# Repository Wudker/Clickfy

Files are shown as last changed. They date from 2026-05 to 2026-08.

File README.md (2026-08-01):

# Clickfy – BLE Multimedia Remote

Clickfy is a compact, keychain-sized multimedia remote based on the ESP32-C3. It communicates through the BLE HID profile and provides dedicated controls for play/pause, next track and previous track. A custom PCB integrates the control buttons, Li-Po battery, status LED and battery-voltage monitoring circuit. The firmware uses sleep modes to reduce power consumption, with development focused on minimizing wake-up and BLE reconnection times.

## Technologies

`ESP32-C3` `C/C++` `Bluetooth Low Energy` `BLE HID` `Li-Po battery` `ADC battery monitoring` `Custom PCB` `Low-power operation`

## Usage and development status

After powering on the device, pair Clickfy with a phone, computer or another BLE-compatible media device and use the three buttons to control playback. The current prototype has been built and tested. Planned improvements include further power optimization, shorter reconnection times and support for additional multimedia functions.

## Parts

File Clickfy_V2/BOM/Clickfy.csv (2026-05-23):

Reference | Qty | Value | Footprint
C1,C3,C6,C7,C11,C14,C15 | 7 | 100n | Capacitor_SMD:C_1206_3216Metric
C2,C10,C12 | 3 | 22u | Capacitor_THT:C_Radial_D4.0mm_H7.0mm_P1.50mm
C4 | 1 | 22u | Capacitor_THT:C_Radial_D5.0mm_H11.0mm_P2.00mm
C5,C8 | 2 | 4.7u
C9,C13 | 2 | 10u
D1 | 1 | LED | LED_THT:LED_D5.0mm
D2,D3 | 2 | LED | LED_SMD:LED_1206_3216Metric
D4 | 1 | SS34 | Diode_SMD:D_SMC
J1 | 1 | USB_C_Receptacle_USB2.0_16P | Connector_USB:USB_C_Receptacle_GCT_USB4125-xx-x_6P_TopMnt_Horizontal
Q1 | 1 | PUMX1 | Package_TO_SOT_SMD:SOT-363_SC-70-6
Q3 | 1 | AO3401A | Package_TO_SOT_SMD:SOT-23
R1,R2,R3,R4,R7,R8,R10,R11,R16,R19,R20 | 11 | 10k | Resistor_SMD:R_1206_3216Metric
R5,R6 | 2 | 5.1K
R9,R12,R13 | 3 | 1k | Resistor_SMD:R_1206_3216Metric
R14 | 1 | 0.4 | Resistor_SMD:R_1206_3216Metric
R15 | 1 | 3k
R17,R18 | 2 | 250k
SW1,SW2,SW3 | 3 | SW_Push | Button_Switch_THT:SW_PUSH_6mm_H5mm
U1 | 1 | USBLC6-2P6 | Package_TO_SOT_SMD:SOT-666
U2 | 1 | ESP32-C3-WROOM-02 | RF_Module:ESP32-C3-WROOM-02
U3 | 1 | CP2104 | Package_DFN_QFN:QFN-24-1EP_4x4mm_P0.5mm_EP2.6x2.6mm
U4 | 1 | TP4056-42-ESOP8 | Package_SO:HSOP-8-1EP_3.9x4.9mm_P1.27mm_EP2.41x3.1mm
U5 | 1 | MCP1825S | Package_SO:TSOP-6_1.65x3.05mm_P0.95mm

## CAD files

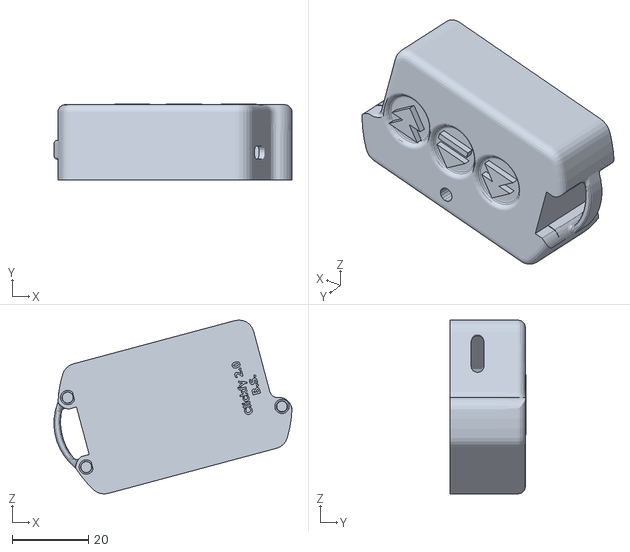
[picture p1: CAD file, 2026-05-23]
Clickfy_V2/Hardware/Model/main.stl
62.6 x 20.1 x 45.8

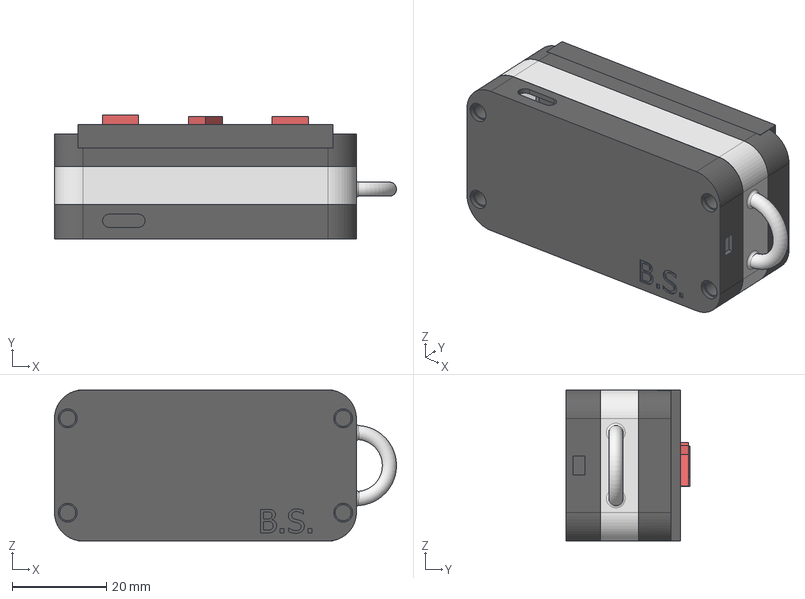
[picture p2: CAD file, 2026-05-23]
Clickfy_V1 (prototype)/Model/main.stp
72.5 x 26.4 x 32.0 mm
rama
flor
button_bottom
button_top
guzik x 2
guzik_szablon

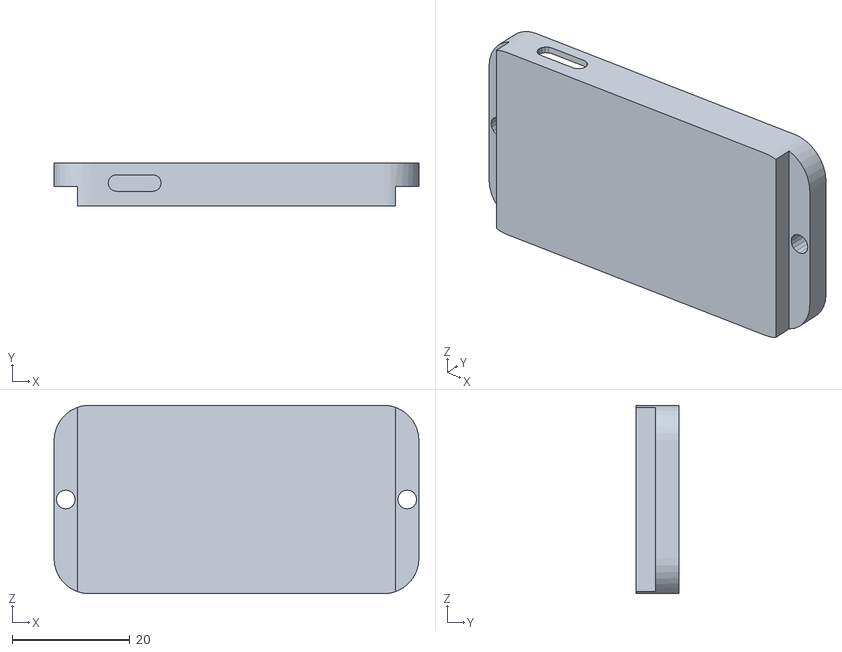
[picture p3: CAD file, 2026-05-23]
Clickfy_V1 (prototype)/Model/rama.stl
62.0 x 7.30 x 32.0

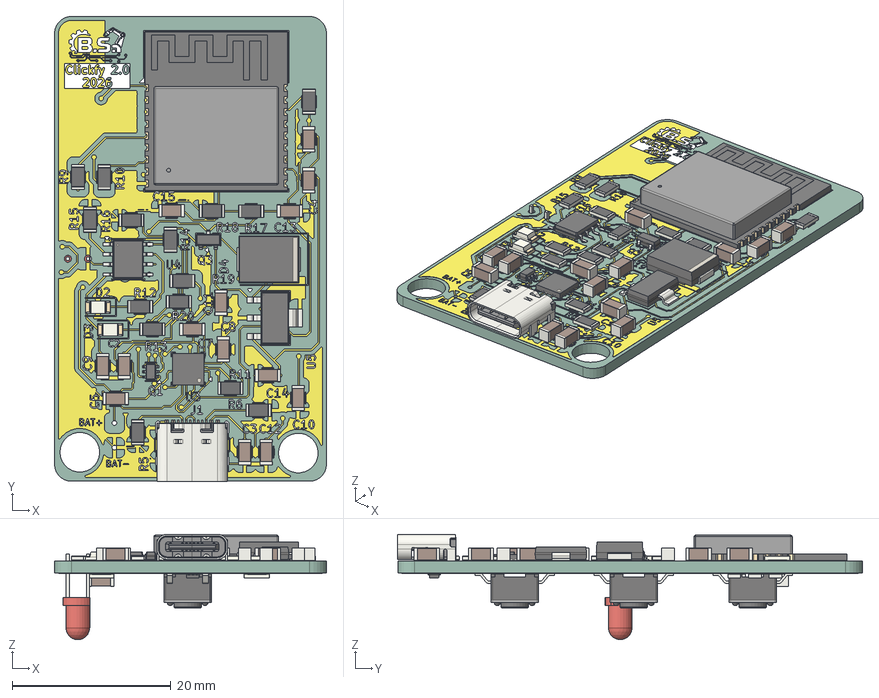
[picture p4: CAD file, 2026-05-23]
Clickfy_V2/Hardware/PCB/Clickfy_v2.step
34.3 x 58.6 x 13.3 mm
R_1206_3216Metric x 20
SOT-223
D_SMC
LED_1206_3216Metric x 2
C_1206_3216Metric x 15
SOT-363_SC-70-6
QFN-24-1EP_4x4mm_P0.5mm_EP2.6x2.6mm
HSOP-8-1EP_3.9x4.9mm_P1.27mm_EP2.41x3.1mm
USB_C_Receptacle_GCT_USB4105-xx-A_16P_TopMnt_Horizontal
ESP32-C3-WROOM-02
SOT-23
SW_Push_1P1T_NO_E-Switch_TL3301NxxxxxG x 3
LED_D3.0mm
SOT-666
Clickfy_copper
Clickfy_silkscreen x 2
Clickfy_PCB

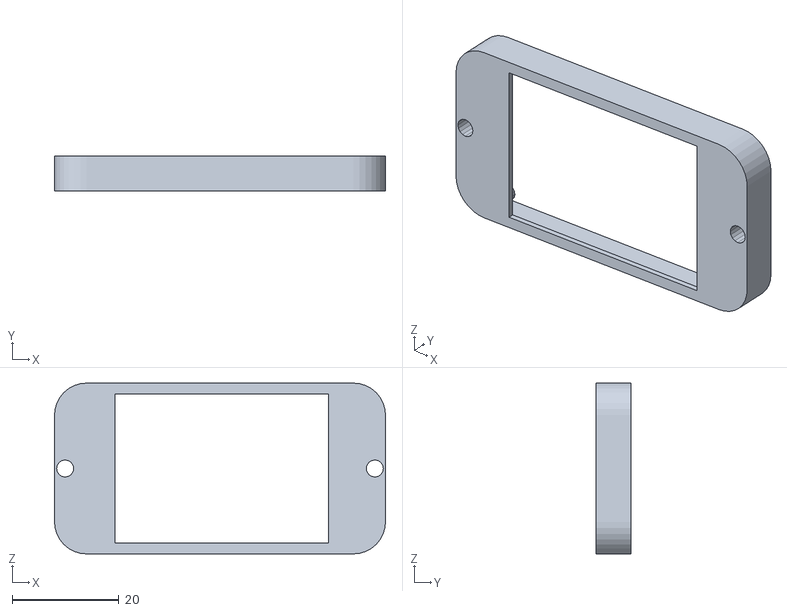
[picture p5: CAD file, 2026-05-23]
Clickfy_V1 (prototype)/Model/flor.stl
62.0 x 6.50 x 32.0

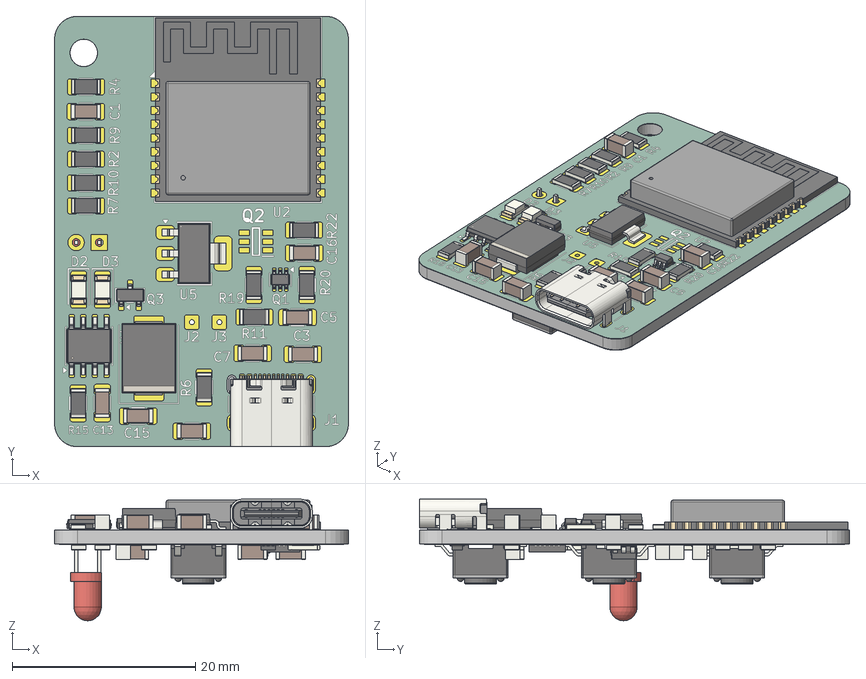
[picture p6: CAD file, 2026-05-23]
Clickfy_V2/Hardware/Model/Clickfy_v3.step
32.1 x 47.0 x 13.3 mm
R_1206_3216Metric x 22
HSOP-8-1EP_3.9x4.9mm_P1.27mm_EP2.41x3.1mm
USB_C_Receptacle_GCT_USB4105-xx-A_16P_TopMnt_Horizontal
C_1206_3216Metric x 16
SOT-223
D_SMC
SOT-363_SC-70-6
ESP32-C3-WROOM-02
LED_1206_3216Metric x 2
SOT-23
LED_D3.0mm
SW_Push_1P1T_NO_E-Switch_TL3301NxxxxxG x 3
QFN-24-1EP_4x4mm_P0.5mm_EP2.6x2.6mm
SOT-23-6
SOT-666
Clickfy_copper
Clickfy_silkscreen x 2
Clickfy_soldermask x 2
Clickfy_PCB

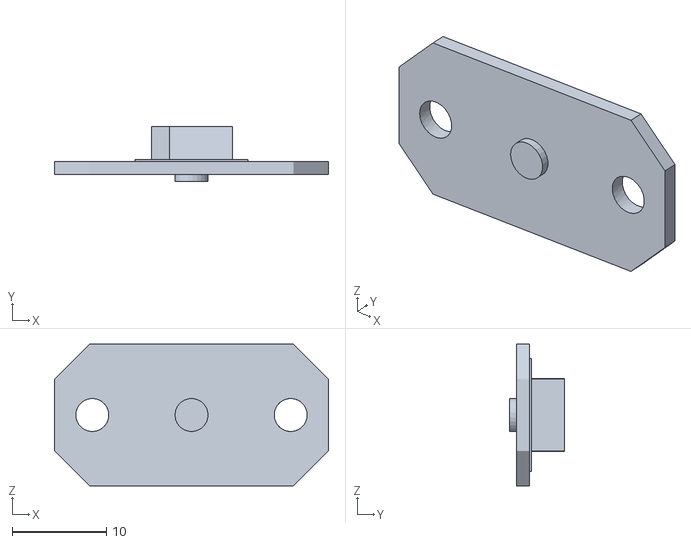
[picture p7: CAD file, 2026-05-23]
Clickfy_V1 (prototype)/Model/guzik.stl
29.0 x 5.85 x 15.0

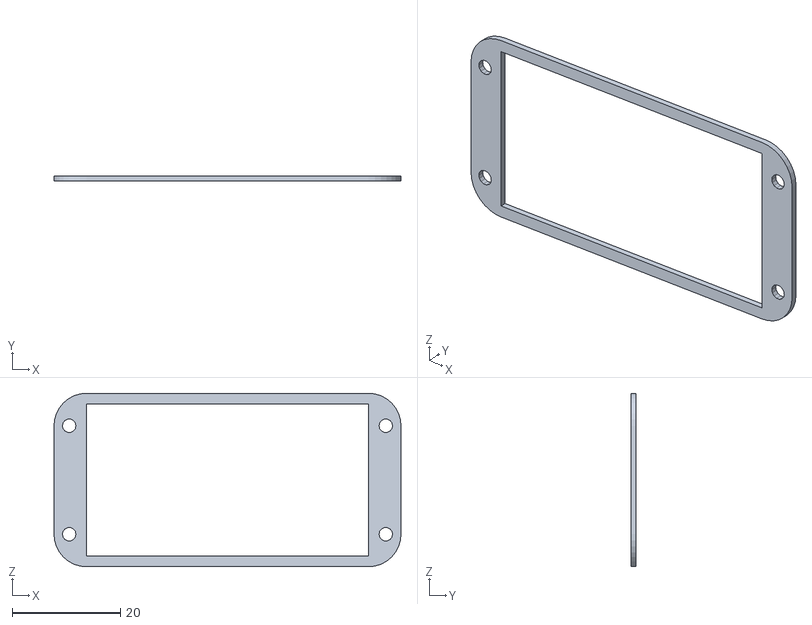
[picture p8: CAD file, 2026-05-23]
Clickfy_V1 (prototype)/Model/redline.stl
64.0 x 1.00 x 32.0

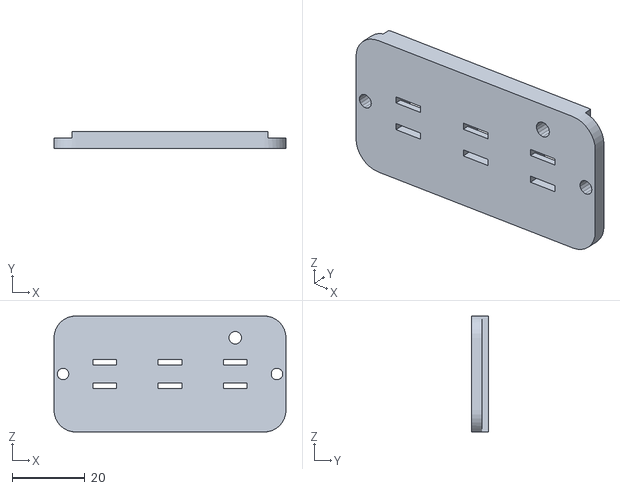
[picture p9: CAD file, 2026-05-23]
Clickfy_V1 (prototype)/Model/button_bottom.stl
64.0 x 4.80 x 32.0

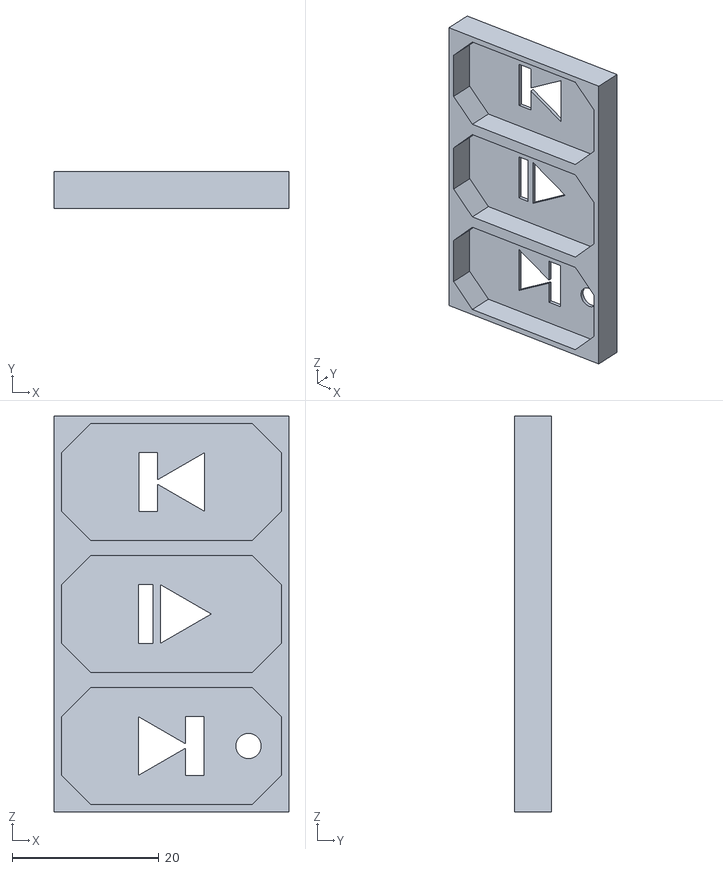
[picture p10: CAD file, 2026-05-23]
Clickfy_V1 (prototype)/Model/button_top.stl
32.0 x 5.00 x 54.0

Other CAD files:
Clickfy_V1 (prototype)/Model/guzik_szablon.stl
Clickfy_V1 (prototype)/Model/bateria_prop.ipt
Clickfy_V1 (prototype)/Model/button_bottom.ipt
Clickfy_V1 (prototype)/Model/button_top.ipt
Clickfy_V1 (prototype)/Model/flor.ipt
Clickfy_V1 (prototype)/Model/guzik.ipt
Clickfy_V1 (prototype)/Model/guzik_szablon.ipt
Clickfy_V1 (prototype)/Model/main.iam
Clickfy_V1 (prototype)/Model/main.stl
Clickfy_V1 (prototype)/Model/rama.ipt
Clickfy_V1 (prototype)/Model/redline.ipt
Clickfy_V2/Hardware/Model/Battery_atrapa.ipt
Clickfy_V2/Hardware/Model/Clickfy_v3/Clickfy_v3/Clickfy_v3.ipt
Clickfy_V2/Hardware/Model/Clickfy_v3/Clickfy_v3/OldVersions/Clickfy_v3.0002.ipt
Clickfy_V2/Hardware/Model/Main_bottom.ipt
Clickfy_V2/Hardware/Model/guzik_musik.ipt
Clickfy_V2/Hardware/Model/guzik_stop.ipt
Clickfy_V2/Hardware/Model/main.iam
Clickfy_V2/Hardware/Model/mid.ipt
Clickfy_V2/Hardware/Model/top.ipt
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

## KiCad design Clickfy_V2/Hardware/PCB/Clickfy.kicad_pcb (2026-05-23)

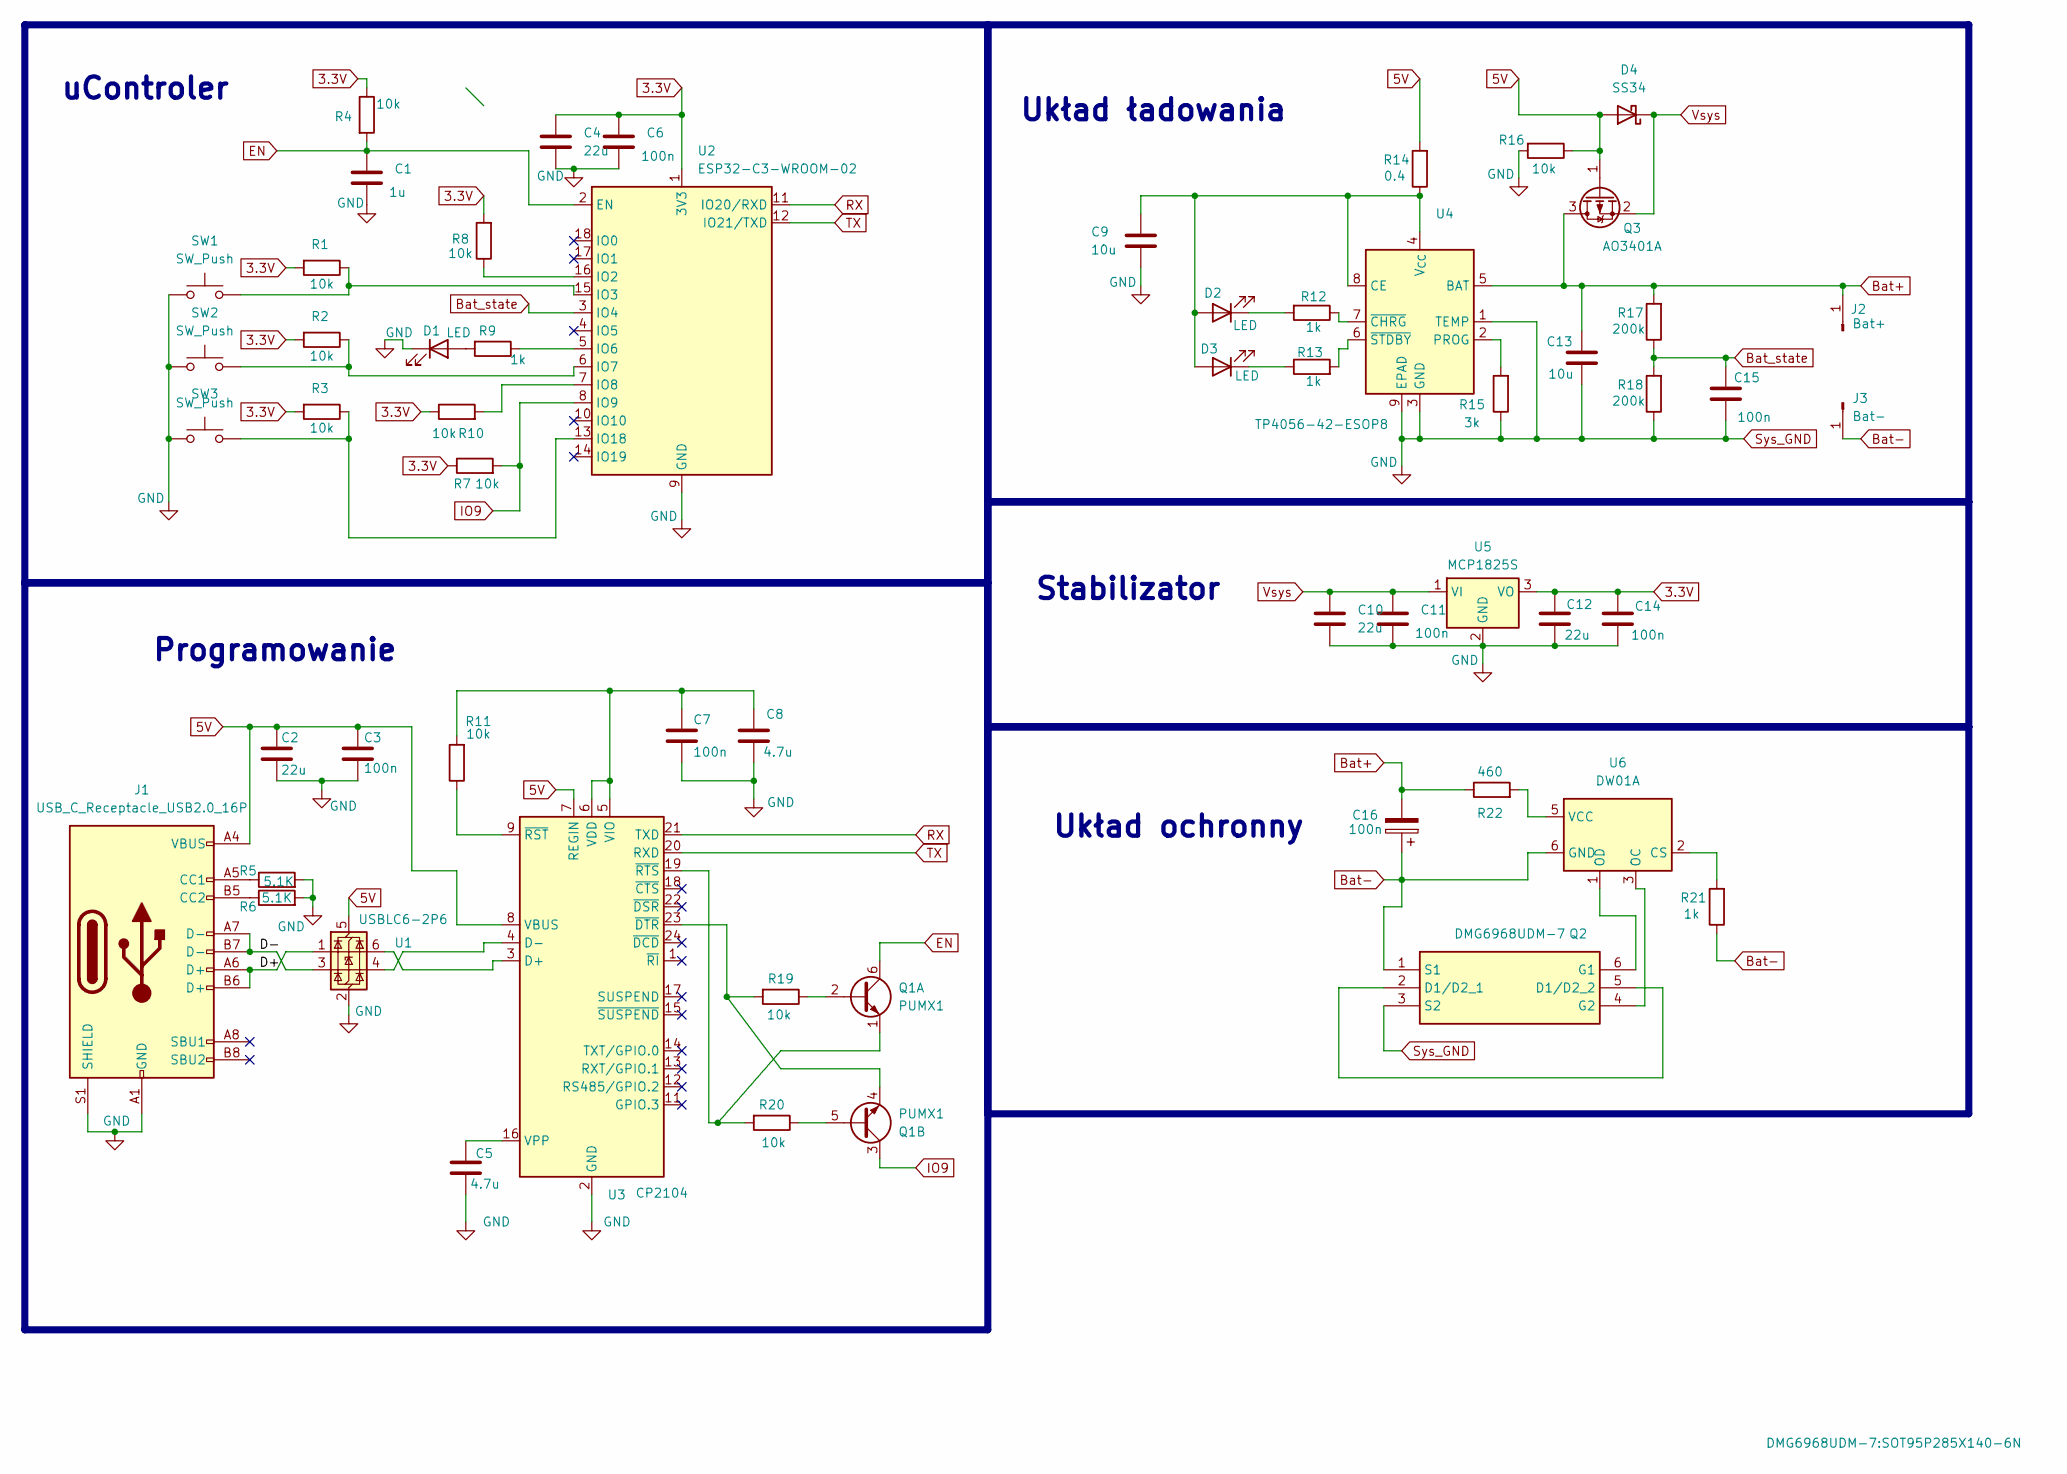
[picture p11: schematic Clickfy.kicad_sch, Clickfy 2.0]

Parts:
C1: 1u; C_1206_3216Metric
C2, C4, C10, C12: 22u; C_1206_3216Metric
C3, C6, C7, C11, C14, C15, C16: 100n; C_1206_3216Metric
C5, C8: 4.7u; C_1206_3216Metric
C9, C13: 10u; C_1206_3216Metric
D1: LED; LED_D3.0mm
D2, D3: LED; LED_1206_3216Metric
D4: SS34; D_SMC
J1: USB_C_Receptacle_USB2.0_16P; USB_C_Receptacle_GCT_USB4105-xx-A_16P_TopMnt_Horizontal
J2: Bat+; SolderWire-0.1sqmm_1x01_D0.4mm_OD1mm
J3: Bat-; SolderWire-0.1sqmm_1x01_D0.4mm_OD1mm
Q1: PUMX1; SOT-363_SC-70-6
Q2: DMG6968UDM-7; SOT95P285X140-6N; Manufacturer_Part_Number DMG6968UDM-7
Q3: AO3401A; SOT-23
R1, R2, R3, R4, R7, R8, R10, R11, R16, R19, R20: 10k; R_1206_3216Metric
R5, R6: 5.1K; R_1206_3216Metric
R9, R12, R13, R21: 1k; R_1206_3216Metric
R14: 0.4; R_1206_3216Metric
R15: 3k; R_1206_3216Metric
R17, R18: 200k; R_1206_3216Metric
R22: 460; R_1206_3216Metric
SW1, SW2, SW3: SW_Push; SW_Push_1P1T_NO_E-Switch_TL3301NxxxxxG
U1: USBLC6-2P6; SOT-666
U2: ESP32-C3-WROOM-02
U3: CP2104; QFN-24-1EP_4x4mm_P0.5mm_EP2.6x2.6mm
U4: TP4056-42-ESOP8; HSOP-8-1EP_3.9x4.9mm_P1.27mm_EP2.41x3.1mm
U5: MCP1825S; SOT-223-3_TabPin2
U6: DW01A; SOT-23-6

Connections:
3.3V: C4.1, C6.1, C12.1, C14.1, R1.2, R2.2, R3.2, R4.1, R7.1, R8.2, R10.1, U2.1 (3V3), U5.3 (VO)
5V: C2.1, C3.1, D4.2 (A), J1.A4 (VBUS), J1.A9 (VBUS), J1.B4 (VBUS), J1.B9 (VBUS), Q3.1 (G), R14.2, R16.1, U1.5 (VBUS), U3.7 (REGIN), U3.8 (VBUS)
/D+: J1.A6 (D+), J1.B6 (D+), U1.1 (I/O1)
/D-: J1.A7 (D-), J1.B7 (D-), U1.3 (I/O2)
Bat+: C13.1, C16.2, J2.1, Q3.3 (D), R17.2, R22.1, U4.5 (BAT)
Bat-: C16.1, J3.1, Q2.1 (S1), R21.1, U6.6 (GND)
Bat_state: C15.1, R17.1, R18.2, U2.3 (IO4)
EN: C1.1, Q1.6 (C1), R4.2, U2.2 (EN)
IO9: Q1.3 (C2), R7.2, U2.8 (IO9)
unnamed: D1.2 (A), R9.2
unnamed: C9.1, D2.2 (A), D3.2 (A), R14.1, U4.4 (V_{CC}), U4.8 (CE)
unnamed: D2.1 (K), R12.2
unnamed: D3.1 (K), R13.1
unnamed: J1.A5 (CC1), R5.1
unnamed: J1.B5 (CC2), R6.1
unnamed: Q1.2 (B1), R19.1
unnamed: Q1.1 (E1), R20.2, U3.19 (~RTS)
unnamed: Q1.5 (B2), R20.1
unnamed: Q1.4 (E2), R19.2, U3.23 (~DTR)
unnamed: Q2.2 (D1/D2_1), Q2.5 (D1/D2_2)
unnamed: Q2.6 (G1), U6.1 (OD)
unnamed: Q2.4 (G2), U6.3 (OC)
unnamed: R8.1, U2.16 (IO2)
unnamed: R1.1, SW1.2, U2.15 (IO3)
unnamed: R9.1, U2.5 (IO6)
unnamed: R2.1, SW2.2, U2.6 (IO7)
unnamed: R10.2, U2.7 (IO8)
unnamed: R3.1, SW3.2, U2.13 (IO18)
unnamed: U1.6 (I/O1), U3.3 (D+)
unnamed: U1.4 (I/O2), U3.4 (D-)
unnamed: C7.1, C8.2, R11.2, U3.5 (VIO), U3.6 (VDD)
unnamed: C5.1, U3.16 (VPP)
unnamed: R11.1, U3.9 (~RST)
unnamed: R15.2, U4.2 (PROG)
unnamed: R12.1, U4.7 (~CHRG)
unnamed: R13.2, U4.6 (~STDBY)
unnamed: R21.2, U6.2 (CS)
unnamed: R22.2, U6.5 (VCC)
RX: U2.11 (IO20/RXD), U3.21 (TXD)
Sys_GND: C1.2, C2.2, C3.2, C4.2, C5.2, C6.2, C7.2, C8.1, C9.2, C10.2, C11.2, C12.2, C13.2, C14.2, C15.2, D1.1 (K), J1.A1 (GND), J1.A12 (GND), J1.B1 (GND), J1.B12 (GND), J1.S1 (SHIELD), Q2.3 (S2), R5.2, R6.2, R15.1, R16.2, R18.1, SW1.1, SW2.1, SW3.1, U1.2 (GND), U2.9 (GND), U2.19 (GND), U3.2 (GND), U3.25 (GND), U4.1 (TEMP), U4.3 (GND), U4.9 (EPAD), U5.2 (GND)
TX: U2.12 (IO21/TXD), U3.20 (RXD)
Vsys: C10.1, C11.1, D4.1 (K), Q3.2 (S), U5.1 (VI)

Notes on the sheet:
Stabilizator
Programowanie
uControler
Układ ładowania
Układ ochronny

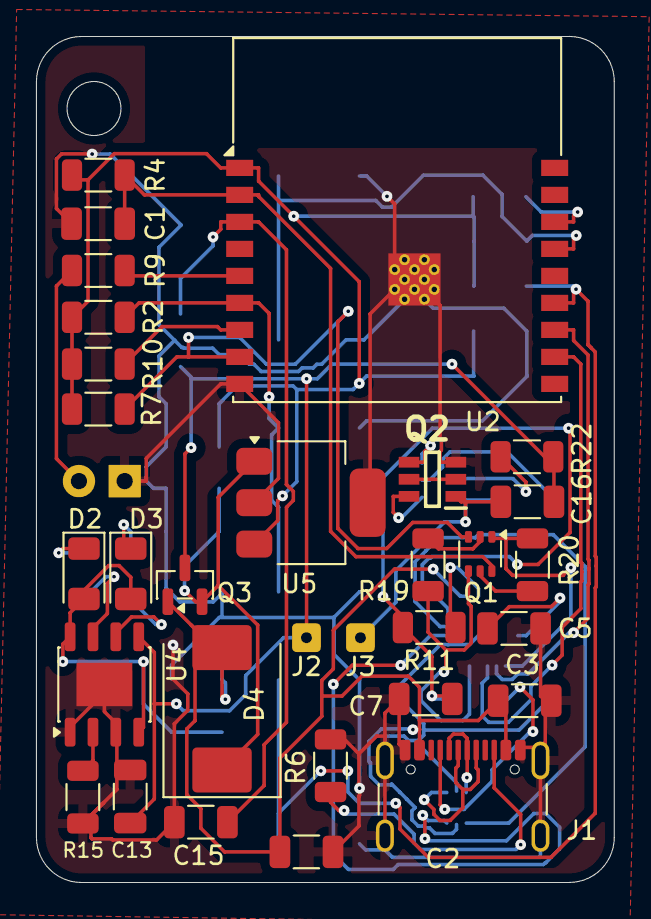
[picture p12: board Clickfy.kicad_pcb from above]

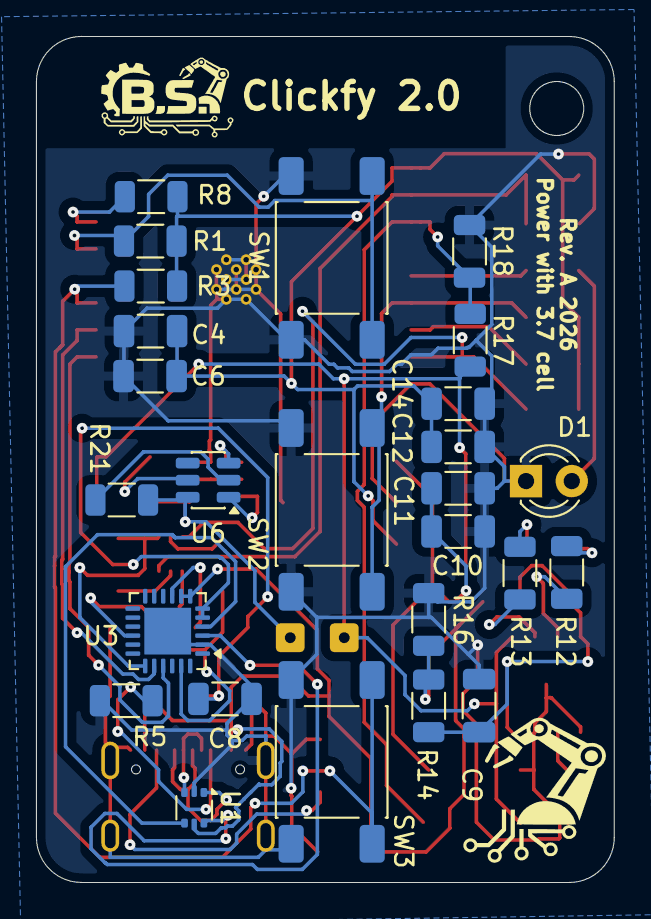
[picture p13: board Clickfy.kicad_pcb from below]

Board: 2 copper layers, 32.1 x 47.0 mm, 57 parts (26 on the bottom side), 42 nets.

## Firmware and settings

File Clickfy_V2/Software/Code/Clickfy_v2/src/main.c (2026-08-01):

#include <stdbool.h>
#include <stdint.h>
#include <stdio.h>
#include <string.h>

#include "driver/adc.h"
#include "driver/gpio.h"
#include "esp_adc_cal.h"
#include "esp_attr.h"
#include "esp_err.h"
#include "esp_log.h"
#include "esp_nimble_hci.h"
#include "esp_pm.h"
#include "esp_sleep.h"
#include "esp_system.h"
#include "esp_timer.h"
#include "freertos/FreeRTOS.h"
#include "freertos/queue.h"
#include "freertos/semphr.h"
#include "freertos/task.h"
#include "host/ble_gap.h"
#include "host/ble_gatt.h"
#include "host/ble_hs.h"
#include "host/ble_hs_mbuf.h"
#include "host/ble_uuid.h"
#include "host/util/util.h"
#include "nimble/nimble_port.h"
#include "nimble/nimble_port_freertos.h"
#include "nvs_flash.h"
#include "services/gap/ble_svc_gap.h"
#include "services/gatt/ble_svc_gatt.h"

#define TAG "Clickfy_2.0"
#define DEVICE_NAME "Clickfy 2.0"
#define MANUFACTURER_NAME "Blough"

#define PLAY_PIN GPIO_NUM_7
#define FORWARD_PIN GPIO_NUM_3
#define PREVIOUS_PIN GPIO_NUM_18
#define LED_PIN GPIO_NUM_6
#define BATTERY_CHANNEL ADC1_CHANNEL_4

#define BUTTON_MASK ((1ULL << PLAY_PIN) | (1ULL << FORWARD_PIN) | (1ULL << PREVIOUS_PIN))

/* Fast advertising is used after boot and disconnect. If the phone does not
 * connect in this time, Bluetooth is stopped before entering light sleep. */
#define FAST_ADV_DURATION_MS 30000
#define CONNECTED_IDLE_TIMEOUT_MS 15000
#define BUTTON_DEBOUNCE_MS 25
#define REPORT_RELEASE_DELAY_MS 25
#define BATTERY_CHECK_INTERVAL_MS (5 * 60 * 1000)

#define BATTERY_DIVIDER_RATIO 2.0f
#define BATTERY_CALIBRATION 1.0f
#define BATTERY_DEFAULT_VREF_MV 1100

#define REPORT_ID_CONSUMER_CONTROL 1
#define REPORT_TYPE_INPUT 1

#define KEY_PLAY_PAUSE 0x00CD
#define KEY_NEXT_TRACK 0x00B5
#define KEY_PREV_TRACK 0x00B6

#define RTC_PENDING_MAGIC_VALUE 0x434C4B59UL
#define COMMAND_QUEUE_LENGTH 4

typedef enum {
    HID_ACCESS_INFO = 1,
    HID_ACCESS_REPORT_MAP,
    HID_ACCESS_INPUT_REPORT,
    HID_ACCESS_PROTOCOL_MODE,
    HID_ACCESS_CONTROL_POINT,
} hid_access_type_t;

static uint8_t ble_addr_type;
static volatile uint16_t current_conn_handle = BLE_HS_CONN_HANDLE_NONE;
static volatile bool input_notify_enabled;
static volatile bool battery_notify_enabled;
static volatile bool ble_stack_synced;
static volatile bool ble_stack_active;
static volatile bool sleep_requested;
static volatile bool sleep_after_disconnect;
static volatile bool suppress_wake_button_until_release;

static uint16_t input_report_handle;
static uint16_t battery_handle;
static uint8_t protocol_mode = 1;
static uint8_t control_point;
static uint8_t input_report_value[2];
static volatile uint8_t cached_battery_level = 100;

static QueueHandle_t command_queue;
static SemaphoreHandle_t ble_host_stopped_sem;
static TaskHandle_t clickfy_task_handle;
static esp_adc_cal_characteristics_t adc_characteristics;
static int64_t boot_started_us;
static volatile TickType_t last_activity_tick;

/* RTC_NOINIT survives esp_restart(). A magic value prevents random power-on
 * contents from being interpreted as a media command. */
RTC_NOINIT_ATTR static uint32_t rtc_pending_magic;
RTC_NOINIT_ATTR static uint16_t rtc_pending_command;

void ble_store_config_init(void);

static void ble_app_advertise(void);
static int ble_gap_event(struct ble_gap_event *event, void *arg);
static void notify_clickfy_task(void);

static const uint8_t hid_report_map[] = {
    0x05, 0x0C,       /* Usage Page (Consumer) */
    0x09, 0x01,       /* Usage (Consumer Control) */
    0xA1, 0x01,       /* Collection (Application) */
    0x85, REPORT_ID_CONSUMER_CONTROL,
    0x19, 0x00,       /* Usage Minimum (Unassigned) */
    0x2A, 0x3C, 0x02, /* Usage Maximum (AC Format) */
    0x15, 0x00,       /* Logical Minimum (0) */
    0x26, 0x3C, 0x02, /* Logical Maximum (572) */
    0x95, 0x01,       /* Report Count (1) */
    0x75, 0x10,       /* Report Size (16) */
    0x81, 0x00,       /* Input (Data, Array, Absolute) */
    0xC0              /* End Collection */
};

static int append_to_mbuf(struct os_mbuf *om, const void *data, uint16_t length)
{
    return os_mbuf_append(om, data, length) == 0 ? 0 : BLE_ATT_ERR_INSUFFICIENT_RES;
}

static int report_reference_access_cb(uint16_t conn_handle, uint16_t attr_handle,
                                      struct ble_gatt_access_ctxt *ctxt, void *arg)
{
    (void)conn_handle;
    (void)attr_handle;
    (void)arg;

    if (ctxt->op != BLE_GATT_ACCESS_OP_READ_DSC) {
        return BLE_ATT_ERR_READ_NOT_PERMITTED;
    }

    const uint8_t report_reference[] = {
        REPORT_ID_CONSUMER_CONTROL,
        REPORT_TYPE_INPUT,
    };
    return append_to_mbuf(ctxt->om, report_reference, sizeof(report_reference));
}

static int hid_access_cb(uint16_t conn_handle, uint16_t attr_handle,
                         struct ble_gatt_access_ctxt *ctxt, void *arg)
{
    (void)conn_handle;
    (void)attr_handle;

    const hid_access_type_t type = (hid_access_type_t)(uintptr_t)arg;
    uint8_t value;
    uint16_t copied;
    int rc;

    switch (type) {
    case HID_ACCESS_INFO: {
        const uint8_t hid_info[] = {0x11, 0x01, 0x00, 0x01};
        return append_to_mbuf(ctxt->om, hid_info, sizeof(hid_info));
    }

    case HID_ACCESS_REPORT_MAP:
        return append_to_mbuf(ctxt->om, hid_report_map, sizeof(hid_report_map));

    case HID_ACCESS_INPUT_REPORT:
        return append_to_mbuf(ctxt->om, input_report_value, sizeof(input_report_value));

    case HID_ACCESS_PROTOCOL_MODE:
        if (ctxt->op == BLE_GATT_ACCESS_OP_READ_CHR) {
            return append_to_mbuf(ctxt->om, &protocol_mode, sizeof(protocol_mode));
        }
        if (ctxt->op != BLE_GATT_ACCESS_OP_WRITE_CHR) {
            return BLE_ATT_ERR_UNLIKELY;
        }
        rc = ble_hs_mbuf_to_flat(ctxt->om, &value, sizeof(value), &copied);
        if (rc != 0 || copied != sizeof(value) || value > 1) {
            return BLE_ATT_ERR_INVALID_ATTR_VALUE_LEN;
        }
        protocol_mode = value;
        return 0;

    case HID_ACCESS_CONTROL_POINT:
        if (ctxt->op != BLE_GATT_ACCESS_OP_WRITE_CHR) {
            return BLE_ATT_ERR_WRITE_NOT_PERMITTED;
        }
        rc = ble_hs_mbuf_to_flat(ctxt->om, &value, sizeof(value), &copied);
        if (rc != 0 || copied != sizeof(value) || value > 1) {
            return BLE_ATT_ERR_INVALID_ATTR_VALUE_LEN;
        }
        control_point = value;
        return 0;
    }

    return BLE_ATT_ERR_UNLIKELY;
}

static int battery_access_cb(uint16_t conn_handle, uint16_t attr_handle,
                             struct ble_gatt_access_ctxt *ctxt, void *arg)
{
    (void)conn_handle;
    (void)attr_handle;
    (void)arg;

    if (ctxt->op != BLE_GATT_ACCESS_OP_READ_CHR) {
        return BLE_ATT_ERR_READ_NOT_PERMITTED;
    }

    const uint8_t level = cached_battery_level;
    return append_to_mbuf(ctxt->om, &level, sizeof(level));
}

static int manufacturer_access_cb(uint16_t conn_handle, uint16_t attr_handle,
                                  struct ble_gatt_access_ctxt *ctxt, void *arg)
{
    (void)conn_handle;
    (void)attr_handle;
    (void)arg;

    if (ctxt->op != BLE_GATT_ACCESS_OP_READ_CHR) {
        return BLE_ATT_ERR_READ_NOT_PERMITTED;
    }
    return append_to_mbuf(ctxt->om, MANUFACTURER_NAME, strlen(MANUFACTURER_NAME));
}

static struct ble_gatt_dsc_def input_report_descriptors[] = {
    {
        .uuid = BLE_UUID16_DECLARE(0x2908),
        .att_flags = BLE_ATT_F_READ | BLE_ATT_F_READ_ENC,
        .access_cb = report_reference_access_cb,
    },
    {0},
};

static const struct ble_gatt_chr_def hid_characteristics[] = {
    {
        .uuid = BLE_UUID16_DECLARE(0x2A4A),
        .access_cb = hid_access_cb,
        .arg = (void *)(uintptr_t)HID_ACCESS_INFO,
        .flags = BLE_GATT_CHR_F_READ | BLE_GATT_CHR_F_READ_ENC,
    },
    {
        .uuid = BLE_UUID16_DECLARE(0x2A4B),
        .access_cb = hid_access_cb,
        .arg = (void *)(uintptr_t)HID_ACCESS_REPORT_MAP,
        .flags = BLE_GATT_CHR_F_READ | BLE_GATT_CHR_F_READ_ENC,
    },
    {
        .uuid = BLE_UUID16_DECLARE(0x2A4D),
        .access_cb = hid_access_cb,
        .arg = (void *)(uintptr_t)HID_ACCESS_INPUT_REPORT,
        .descriptors = input_report_descriptors,
        .flags = BLE_GATT_CHR_F_READ | BLE_GATT_CHR_F_READ_ENC | BLE_GATT_CHR_F_NOTIFY,
        .val_handle = &input_report_handle,
    },
    {
        .uuid = BLE_UUID16_DECLARE(0x2A4E),
        .access_cb = hid_access_cb,
        .arg = (void *)(uintptr_t)HID_ACCESS_PROTOCOL_MODE,
        .flags = BLE_GATT_CHR_F_READ | BLE_GATT_CHR_F_READ_ENC |
                 BLE_GATT_CHR_F_WRITE_NO_RSP | BLE_GATT_CHR_F_WRITE_ENC,
    },
    {
        .uuid = BLE_UUID16_DECLARE(0x2A4C),
        .access_cb = hid_access_cb,
        .arg = (void *)(uintptr_t)HID_ACCESS_CONTROL_POINT,
        .flags = BLE_GATT_CHR_F_WRITE_NO_RSP | BLE_GATT_CHR_F_WRITE_ENC,
    },
    {0},
};

static const struct ble_gatt_chr_def battery_characteristics[] = {
    {
        .uuid = BLE_UUID16_DECLARE(0x2A19),
        .access_cb = battery_access_cb,
        .flags = BLE_GATT_CHR_F_READ | BLE_GATT_CHR_F_NOTIFY,
        .val_handle = &battery_handle,
    },
    {0},
};

static const struct ble_gatt_chr_def device_information_characteristics[] = {
    {
        .uuid = BLE_UUID16_DECLARE(0x2A29),
        .access_cb = manufacturer_access_cb,
        .flags = BLE_GATT_CHR_F_READ,
    },
    {0},
};

static const struct ble_gatt_svc_def gatt_services[] = {
    {
        .type = BLE_GATT_SVC_TYPE_PRIMARY,
        .uuid = BLE_UUID16_DECLARE(0x1812),
        .characteristics = hid_characteristics,
    },
    {
        .type = BLE_GATT_SVC_TYPE_PRIMARY,
        .uuid = BLE_UUID16_DECLARE(0x180F),
        .characteristics = battery_characteristics,
    },
    {
        .type = BLE_GATT_SVC_TYPE_PRIMARY,
        .uuid = BLE_UUID16_DECLARE(0x180A),
        .characteristics = device_information_characteristics,
    },
    {0},
};

static bool command_is_valid(uint16_t command)
{
    return command == KEY_PLAY_PAUSE ||
           command == KEY_NEXT_TRACK ||
           command == KEY_PREV_TRACK;
}

static uint16_t command_from_button_state(uint64_t wake_mask)
{
    if ((wake_mask & (1ULL << PLAY_PIN)) || gpio_get_level(PLAY_PIN) == 0) {
        return KEY_PLAY_PAUSE;
    }
    if ((wake_mask & (1ULL << FORWARD_PIN)) || gpio_get_level(FORWARD_PIN) == 0) {
        return KEY_NEXT_TRACK;
    }
    if ((wake_mask & (1ULL << PREVIOUS_PIN)) || gpio_get_level(PREVIOUS_PIN) == 0) {
        return KEY_PREV_TRACK;
    }
    return 0;
}

static bool any_button_pressed(void)
{
    return gpio_get_level(PLAY_PIN) == 0 ||
           gpio_get_level(FORWARD_PIN) == 0 ||
           gpio_get_level(PREVIOUS_PIN) == 0;
}

static void queue_media_command(uint16_t command)
{
    if (!command_is_valid(command)) {
        return;
    }

    if (xQueueSend(command_queue, &command, 0) != pdTRUE) {
        uint16_t discarded;
        xQueueReceive(command_queue, &discarded, 0);
        xQueueSend(command_queue, &command, 0);
        ESP_LOGW(TAG, "Kolejka polecen byla pelna; usunieto najstarsze polecenie");
    }
}

static bool send_media_command(uint16_t command)
{
    const uint16_t conn_handle = current_conn_handle;
    if (conn_handle == BLE_HS_CONN_HANDLE_NONE || !input_notify_enabled) {
        return false;
    }

    const uint8_t press[] = {
        (uint8_t)(command & 0xFF),
        (uint8_t)(command >> 8),
    };
    const uint8_t release[] = {0x00, 0x00};

    struct os_mbuf *om = ble_hs_mbuf_from_flat(press, sizeof(press));
    if (om == NULL) {
        ESP_LOGE(TAG, "Brak bufora dla raportu HID");
        return false;
    }

    int rc = ble_gattc_notify_custom(conn_handle, input_report_handle, om);
    if (rc != 0) {
        ESP_LOGW(TAG, "Nie wyslano raportu HID; rc=%d", rc);
        return false;
    }

    memcpy(input_report_value, press, sizeof(input_report_value));
    vTaskDelay(pdMS_TO_TICKS(REPORT_RELEASE_DELAY_MS));

    om = ble_hs_mbuf_from_flat(release, sizeof(release));
    if (om != NULL) {
        rc = ble_gattc_notify_custom(conn_handle, input_report_handle, om);
        if (rc != 0) {
            ESP_LOGW(TAG, "Nie wyslano zwolnienia klawisza; rc=%d", rc);
        }
    }
    memcpy(input_report_value, release, sizeof(input_report_value));

    ESP_LOGI(TAG, "Wyslano polecenie HID 0x%04X", command);
    return true;
}

static void send_queued_commands(void)
{
    uint16_t command;

    while (current_conn_handle != BLE_HS_CONN_HANDLE_NONE &&
           input_notify_enabled &&
           xQueuePeek(command_queue, &command, 0) == pdTRUE) {
        if (!send_media_command(command)) {
            break;
        }
        xQueueReceive(command_queue, &command, 0);
    }
}

static uint8_t battery_percent_from_mv(uint32_t millivolts)
{
    static const struct {
        uint16_t millivolts;
        uint8_t percent;
    } curve[] = {
        {4200, 100},
        {4100, 90},
        {4000, 80},
        {3900, 65},
        {3800, 45},
        {3700, 25},
        {3600, 10},
        {3400, 3},
        {3300, 0},
    };

    if (millivolts >= curve[0].millivolts) {
        return 100;
    }
    if (millivolts <= curve[sizeof(curve) / sizeof(curve[0]) - 1].millivolts) {
        return 0;
    }

    for (size_t i = 1; i < sizeof(curve) / sizeof(curve[0]); ++i) {
        if (millivolts >= curve[i].millivolts) {
            const uint32_t voltage_span = curve[i - 1].millivolts - curve[i].millivolts;
            const uint32_t percent_span = curve[i - 1].percent - curve[i].percent;
            return curve[i].percent +
                   (uint8_t)(((millivolts - curve[i].millivolts) * percent_span) /
                             voltage_span);
        }
    }

    return 0;
}

static uint8_t read_battery_level(void)
{
    uint32_t raw_sum = 0;
    const uint32_t samples = 32;

    /* The 200k/200k divider has high output impedance. Several conversions
     * allow the ADC sample capacitor to settle and reduce random noise. */
    (void)adc1_get_raw(BATTERY_CHANNEL);
    for (uint32_t i = 0; i < samples; ++i) {
        raw_sum += adc1_get_raw(BATTERY_CHANNEL);
        vTaskDelay(pdMS_TO_TICKS(1));
    }

    const uint32_t raw_average = raw_sum / samples;
    const uint32_t adc_mv = esp_adc_cal_raw_to_voltage(raw_average, &adc_characteristics);
    const uint32_t battery_mv =
        (uint32_t)(adc_mv * BATTERY_DIVIDER_RATIO * BATTERY_CALIBRATION);
    const uint8_t percentage = battery_percent_from_mv(battery_mv);

    ESP_LOGI(TAG, "Bateria: %lu mV, %u%%",
             (unsigned long)battery_mv, percentage);
    return percentage;
}

static void update_battery_level(void)
{
    const uint8_t previous = cached_battery_level;
    cached_battery_level = read_battery_level();

    if (battery_notify_enabled &&
        current_conn_handle != BLE_HS_CONN_HANDLE_NONE &&
        cached_battery_level != previous) {
        const uint8_t level = cached_battery_level;
        struct os_mbuf *om = ble_hs_mbuf_from_flat(&level, sizeof(level));
        if (om != NULL) {
            const int rc =
                ble_gattc_notify_custom(current_conn_handle, battery_handle, om);
            if (rc != 0) {
                ESP_LOGW(TAG, "Nie wyslano poziomu baterii; rc=%d", rc);
            }
        }
    }
}

static void pulse_low_battery_led(TickType_t *last_blink)
{
    const uint8_t level = cached_battery_level;
    if (level > 20) {
        gpio_set_level(LED_PIN, 0);
        return;
    }

    const TickType_t now = xTaskGetTickCount();
    const TickType_t interval = pdMS_TO_TICKS(level <= 5 ? 2000 : 10000);
    if (now - *last_blink < interval) {
        return;
    }

    *last_blink = now;
    gpio_set_level(LED_PIN, 1);
    vTaskDelay(pdMS_TO_TICKS(level <= 5 ? 50 : 20));
    gpio_set_level(LED_PIN, 0);
}

static void notify_clickfy_task(void)
{
    if (clickfy_task_handle != NULL) {
        xTaskNotifyGive(clickfy_task_handle);
    }
}

static void mark_activity(void)
{
    last_activity_tick = xTaskGetTickCount();
    sleep_requested = false;
    sleep_after_disconnect = false;
}

static void IRAM_ATTR button_isr_handler(void *arg)
{
    (void)arg;
    BaseType_t higher_priority_task_woken = pdFALSE;

    if (clickfy_task_handle != NULL) {
        vTaskNotifyGiveFromISR(clickfy_task_handle, &higher_priority_task_woken);
    }
    if (higher_priority_task_woken == pdTRUE) {
        portYIELD_FROM_ISR();
    }
}

static void configure_hardware(void)
{
    gpio_config_t output_config = {
        .pin_bit_mask = 1ULL << LED_PIN,
        .mode = GPIO_MODE_OUTPUT,
        .pull_up_en = GPIO_PULLUP_DISABLE,
        .pull_down_en = GPIO_PULLDOWN_DISABLE,
        .intr_type = GPIO_INTR_DISABLE,
    };
    ESP_ERROR_CHECK(gpio_config(&output_config));
    gpio_set_level(LED_PIN, 0);

    gpio_config_t button_config = {
        .pin_bit_mask = BUTTON_MASK,
        .mode = GPIO_MODE_INPUT,
        .pull_up_en = GPIO_PULLUP_ENABLE,
        .pull_down_en = GPIO_PULLDOWN_DISABLE,
        .intr_type = GPIO_INTR_NEGEDGE,
    };
    ESP_ERROR_CHECK(gpio_config(&button_config));

    esp_err_t err = gpio_install_isr_service(ESP_INTR_FLAG_IRAM);
    if (err != ESP_OK && err != ESP_ERR_INVALID_STATE) {
        ESP_ERROR_CHECK(err);
    }
    ESP_ERROR_CHECK(gpio_isr_handler_add(PLAY_PIN, button_isr_handler, NULL));
    ESP_ERROR_CHECK(gpio_isr_handler_add(FORWARD_PIN, button_isr_handler, NULL));
    ESP_ERROR_CHECK(gpio_isr_handler_add(PREVIOUS_PIN, button_isr_handler, NULL));

    adc1_config_width(ADC_WIDTH_BIT_12);
    adc1_config_channel_atten(BATTERY_CHANNEL, ADC_ATTEN_DB_11);
    esp_adc_cal_characterize(ADC_UNIT_1, ADC_ATTEN_DB_11, ADC_WIDTH_BIT_12,
                             BATTERY_DEFAULT_VREF_MV, &adc_characteristics);
}
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
void app_main(void)
{
    boot_started_us = esp_timer_get_time();
    last_activity_tick = xTaskGetTickCount();
    initialize_nvs();
    configure_power_management();
    configure_hardware();

    command_queue = xQueueCreate(COMMAND_QUEUE_LENGTH, sizeof(uint16_t));
    ble_host_stopped_sem = xSemaphoreCreateBinary();
    if (command_queue == NULL || ble_host_stopped_sem == NULL) {
        ESP_LOGE(TAG, "Nie utworzono obiektow FreeRTOS");
        return;
    }

    cached_battery_level = read_battery_level();

    if (esp_reset_reason() == ESP_RST_SW &&
        rtc_pending_magic == RTC_PENDING_MAGIC_VALUE &&
        command_is_valid(rtc_pending_command)) {
        queue_media_command(rtc_pending_command);
        suppress_wake_button_until_release = true;
        ESP_LOGI(TAG, "Zapamietano polecenie z przycisku wybudzajacego");
    }
    rtc_pending_magic = 0;
    rtc_pending_command = 0;

    BaseType_t task_result =
        xTaskCreate(clickfy_task, "clickfy", 4096, NULL, 5, &clickfy_task_handle);
    if (task_result != pdPASS) {
        ESP_LOGE(TAG, "Nie utworzono zadania Clickfy");
        return;
    }

    if (!start_ble_stack()) {
        ESP_LOGE(TAG, "Uruchomienie BLE nie powiodlo sie");
    }
}

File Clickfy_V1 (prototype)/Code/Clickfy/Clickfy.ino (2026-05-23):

#include <BleKeyboard.h>
#include "esp_sleep.h"
#include "driver/gpio.h"

// ---------------------------------------------------------
// Piny Clickify - zgodnie z Twoją płytką
// ---------------------------------------------------------
#define PLAY_PIN       7
#define FORWARD_PIN    3
#define PREVIOUS_PIN   18
#define LED_PIN        6
#define BATTERY_PIN    4

// ---------------------------------------------------------
// BLE
// ---------------------------------------------------------
BleKeyboard keyboard("Clickify", "Blough", 100);

// ---------------------------------------------------------
// Parametry
// ---------------------------------------------------------
const unsigned long DEBOUNCE_DELAY = 50;

// Po ilu ms bez połączenia BLE usypiać urządzenie
const unsigned long NO_CONNECTION_SLEEP_MS = 30000;

// Co ile sprawdzać baterię
const unsigned long BATTERY_CHECK_INTERVAL_MS = 15000;

// Progi baterii
const float LOW_BATTERY_VOLTAGE = 3.55;
const float CRITICAL_BATTERY_VOLTAGE = 3.30;

// Dzielnik 200k + 200k
const float BATTERY_DIVIDER_RATIO = 2.0;
const float BATTERY_CALIBRATION = 1.00;

// ---------------------------------------------------------
// Zmienne
// ---------------------------------------------------------
unsigned long lastDebounceTime = 0;
unsigned long lastActivityTime = 0;
unsigned long bootTime = 0;
unsigned long lastBatteryCheckTime = 0;
unsigned long lastLowBatteryBlinkTime = 0;

bool lastPlayState = HIGH;
bool lastForwardState = HIGH;
bool lastPrevState = HIGH;

bool lowBattery = false;
bool criticalBattery = false;

// ---------------------------------------------------------
// Funkcje pomocnicze
// ---------------------------------------------------------

bool anyButtonPressed() {
  return digitalRead(PLAY_PIN) == LOW ||
         digitalRead(FORWARD_PIN) == LOW ||
         digitalRead(PREVIOUS_PIN) == LOW;
}

float readBatteryVoltage() {
  const int samples = 16;
  uint32_t sumMv = 0;

  for (int i = 0; i < samples; i++) {
    sumMv += analogReadMilliVolts(BATTERY_PIN);
    delay(2);
  }

  float adcVoltage = (sumMv / (float)samples) / 1000.0;
  float batteryVoltage = adcVoltage * BATTERY_DIVIDER_RATIO * BATTERY_CALIBRATION;

  return batteryVoltage;
}

int batteryPercentFromVoltage(float voltage) {
  if (voltage >= 4.20) return 100;
  if (voltage <= 3.30) return 0;

  return (int)((voltage - 3.30) * 100.0 / (4.20 - 3.30));
}

void updateBatteryState() {
  float batteryVoltage = readBatteryVoltage();
  int batteryPercent = batteryPercentFromVoltage(batteryVoltage);

  lowBattery = batteryVoltage <= LOW_BATTERY_VOLTAGE;
  criticalBattery = batteryVoltage <= CRITICAL_BATTERY_VOLTAGE;

  keyboard.setBatteryLevel(batteryPercent);

  Serial.print("Bateria: ");
  Serial.print(batteryVoltage, 3);
  Serial.print(" V, ");
  Serial.print(batteryPercent);
  Serial.println(" %");
}

void handleLowBatteryLed() {
  if (!lowBattery) {
    digitalWrite(LED_PIN, LOW);
    return;
  }

  unsigned long now = millis();

  if (criticalBattery) {
    // Krytycznie niska bateria: 50 ms co 1 s
    if (now - lastLowBatteryBlinkTime >= 1000) {
      lastLowBatteryBlinkTime = now;
      digitalWrite(LED_PIN, HIGH);
      delay(50);
      digitalWrite(LED_PIN, LOW);
    }
  } else {
    // Niska bateria: 20 ms co 2 s
    if (now - lastLowBatteryBlinkTime >= 2000) {
      lastLowBatteryBlinkTime = now;
      digitalWrite(LED_PIN, HIGH);
      delay(20);
      digitalWrite(LED_PIN, LOW);
    }
  }
}

void sendCommandForButton(uint8_t buttonPin) {
  if (!keyboard.isConnected()) {
    return;
  }

  if (buttonPin == PLAY_PIN) {
    Serial.println("Akcja: PLAY/PAUSE");
    keyboard.write(KEY_MEDIA_PLAY_PAUSE);
  }
  else if (buttonPin == FORWARD_PIN) {
    Serial.println("Akcja: NEXT");
    keyboard.write(KEY_MEDIA_NEXT_TRACK);
  }
  else if (buttonPin == PREVIOUS_PIN) {
    Serial.println("Akcja: PREVIOUS");
    keyboard.write(KEY_MEDIA_PREVIOUS_TRACK);
  }

  lastActivityTime = millis();
}

void setupWakeupPinsForLightSleep() {
  // Przyciski są do GND, więc wybudzanie po stanie LOW.
  gpio_wakeup_enable((gpio_num_t)PLAY_PIN, GPIO_INTR_LOW_LEVEL);
  gpio_wakeup_enable((gpio_num_t)FORWARD_PIN, GPIO_INTR_LOW_LEVEL);
  gpio_wakeup_enable((gpio_num_t)PREVIOUS_PIN, GPIO_INTR_LOW_LEVEL);

  esp_sleep_enable_gpio_wakeup();
}

void goToLightSleepWhenDisconnected() {
  Serial.println("Brak polaczenia BLE. Przechodze w light-sleep.");

  digitalWrite(LED_PIN, LOW);
  delay(50);
  Serial.flush();

  setupWakeupPinsForLightSleep();

  esp_light_sleep_start();

  // Po wybudzeniu z light-sleep robimy restart.
  // To jest celowe: BLE startuje wtedy czysto od nowa
  // i nie zostaje w dziwnym stanie po wyjsciu ze sleepa.
  ESP.restart();
}

// ---------------------------------------------------------
// SETUP
// ---------------------------------------------------------

void setup() {
  Serial.begin(115200);
  delay(300);

  // Obniżenie taktowania CPU. Zmniejsza pobór w stanie aktywnym.
  // Dla ESP32-C3 80 MHz jest bezpieczne.
  setCpuFrequencyMhz(80);

  pinMode(PLAY_PIN, INPUT_PULLUP);
  pinMode(FORWARD_PIN, INPUT_PULLUP);
  pinMode(PREVIOUS_PIN, INPUT_PULLUP);

  pinMode(LED_PIN, OUTPUT);
  digitalWrite(LED_PIN, LOW);

  pinMode(BATTERY_PIN, INPUT);
  analogSetPinAttenuation(BATTERY_PIN, ADC_11db);

  keyboard.begin();

  bootTime = millis();
  lastActivityTime = millis();
  lastBatteryCheckTime = millis();

  lastPlayState = digitalRead(PLAY_PIN);
  lastForwardState = digitalRead(FORWARD_PIN);
  lastPrevState = digitalRead(PREVIOUS_PIN);

  updateBatteryState();

  Serial.println("Clickify gotowy. Szukaj mnie w Bluetooth.");
}

// ---------------------------------------------------------
// LOOP
// ---------------------------------------------------------
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

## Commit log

2026-05-23 Revise README with detailed project information
    Expanded project description, added features, hardware, software, challenges, and current status sections to README.
2026-05-23 Create PCB
